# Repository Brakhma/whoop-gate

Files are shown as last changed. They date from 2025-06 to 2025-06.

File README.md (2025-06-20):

# whoop-gate  
Ворота для гонок на маленьких квадрокоптерах.  

**hexgate2.ino** Вторая версия прошивки (кнопка и несколько режимов) под LGT8F328P.  
**hexgate2_nano.ino** Версия прошивки под Arduino nano (отличается только код проверки напряжения батареи).  
**tor4.ino** Флаг с анимацией огня.  

**Фичи:**  
Ворота работают от одной батарейки (любой 1s литий), я использую 18650, какие-либо регуляторы, стабилизаторы step-up не требуются.  
В отличии от ворот на esp минимальное энергопотребление, нет фона на 2,4 GHz  
Есть защита от переразряда батарейки (ворота мигают красным на 3в, на 2.9 засыпают)   
7 режимов свечения перелючаемых по кнопке:  
**Сканер** (как в гексагонах первой версии)   
**Огонь** Анимация огня горящего с двух сторон ленты навстречу друг другу. Если сложить концы ленты вниз то получится огненное кольцо.   
**Радуга** Плавное изменение цвета по всей ленте  
**Фейд** Плавное изменение цвета с затуханием  
**Сплошной красный**  
**Сплошной зелёный**  
**Кометы** По кругу двигаются несколько групп диодов с затухающим хвостом плавно меняющие цвет.  

**Советы**  
Лента используется пятивольтовая WS2812 + и - ленты на холдер батарейки, data на D2 LGT\Arduino. Кнопка замыкает D3 на землю  
Не забудьте указать в коде точное количество диодов.  
LGT прошивайте с clock divider 2  
Для выхода из режимма "сканер" надо нажать кнопку когда светодиоды возвращаются к началу ленты, либо просто нажать и подождать до завершения анимации.  
Ток на воротах зависит от количества диодов и анимации (радуга, фейд, огонь - дороже по энергии, кометы - дешевле)  

Если не знаете что такое LGT и как с ней работать, можете почитать тут:  
[https://alexgyver.ru/lessons/lgt8f328/](https://alexgyver.ru/lessons/lgt8f328/)  
[https://htrd.su/blog/2022/12/04/lgt8fx-lgt8328p/](https://htrd.su/blog/2022/12/04/lgt8fx-lgt8328p/)  
[https://arduino.ru/forum/apparatnye-voprosy/obzor-klona-megi328-lgt8f328p](https://arduino.ru/forum/apparatnye-voprosy/obzor-klona-megi328-lgt8f328p)  
[http://www.prodesign.com.cn/](http://www.prodesign.com.cn/lgt8f328p/)  
  
**UPD** Добавлены модели 19 сантиметровых колец. Кольцо печатается на столе 22х22 без окантовки с кастомной поддержкой (только там где крепится коробка). Заполнение в принципе любое, 10-15 процентов - нормально. Лента WS2812, электроника - LGT8F328P. Клеммы брал [здесь](https://aliexpress.ru/item/1005004432819933.html ) Размеры клеммы в папке с моделью. Количество диодов в прошивке поменяйте под ваш монтаж и плотность ленты, лучше использовать ленту 60led\m. Коробка приклеивается к кольцу суперклеем, к ней привинчивается и, если надо, фиксируется к кольцу на термоклей колдер с клеммами.  
  
[Выглядят вот так](https://t.me/epicwin_ru/109?comment=413).  
[Пример пролёта вот](https://t.me/tagwhoops/1202).  
  
Донаты можно сюда: bc1qfcdmn7tspm0x5qac7ut3yl72tq5az4gx7qjkfs

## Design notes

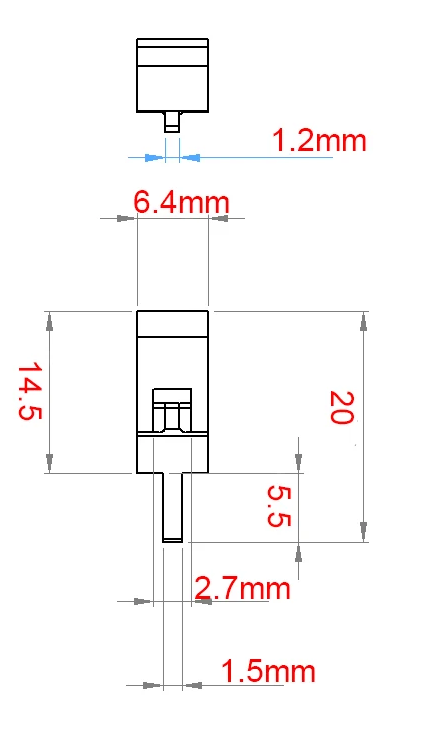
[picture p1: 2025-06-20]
epic_gate(19cm)/klemma.png

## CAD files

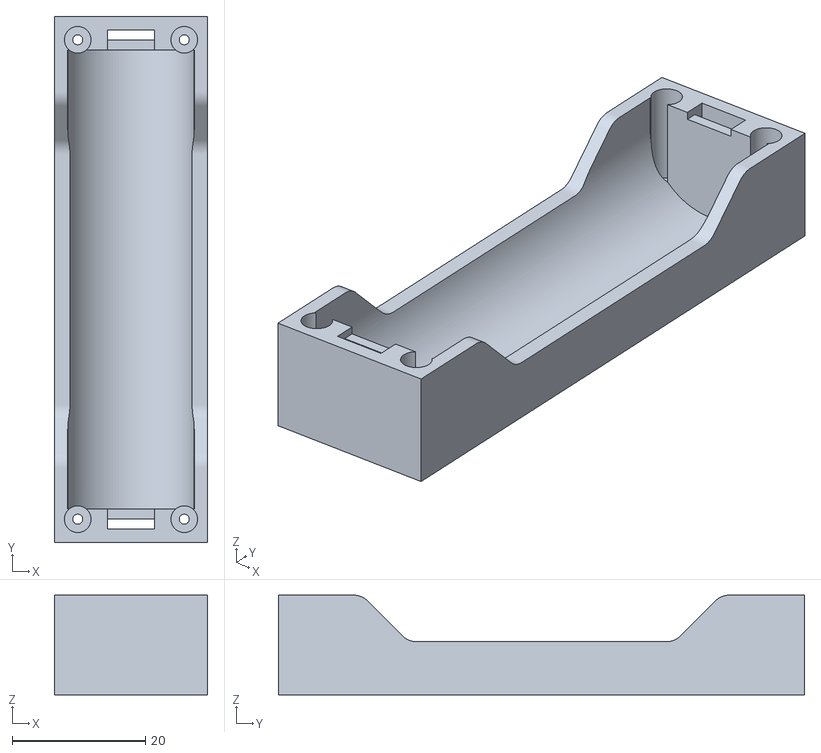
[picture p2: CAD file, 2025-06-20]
epic_gate(19cm)/ring_holder.stl
23.0 x 79.0 x 15.0

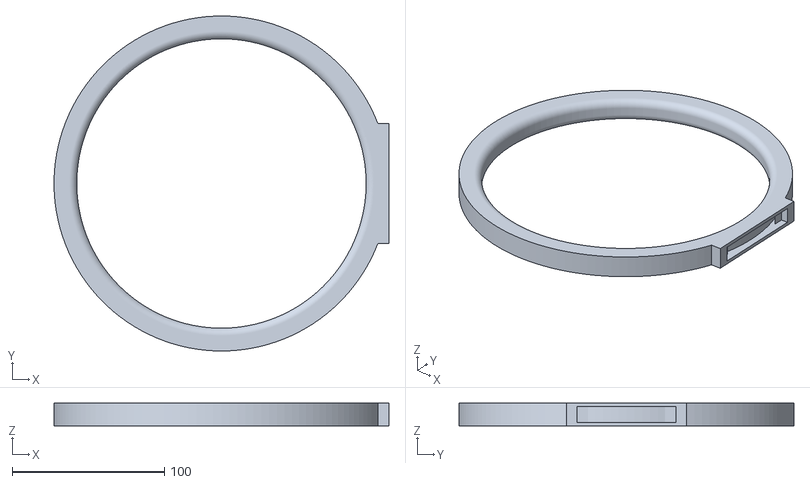
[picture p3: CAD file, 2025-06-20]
epic_gate(19cm)/ring.stl
220.0 x 220.0 x 15.0

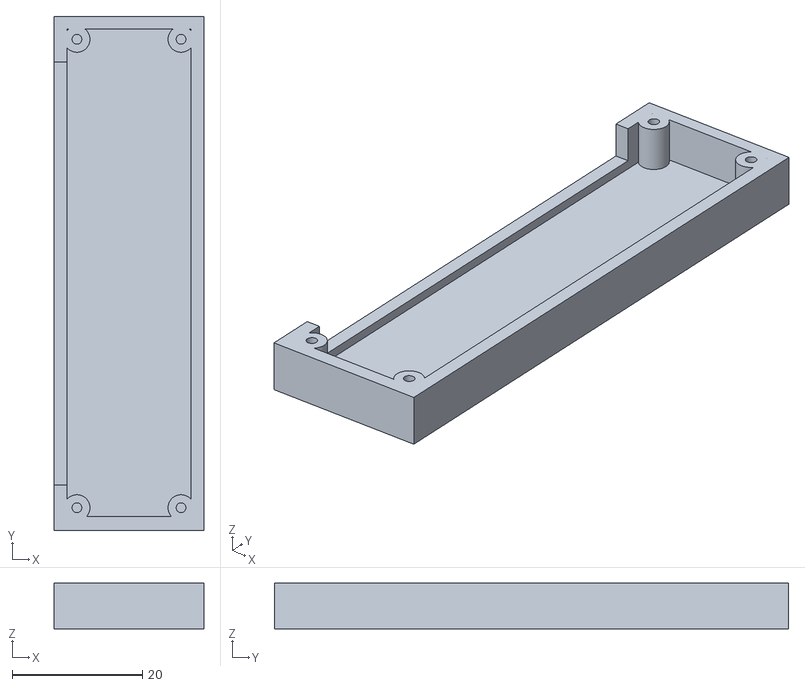
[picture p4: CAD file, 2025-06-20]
epic_gate(19cm)/ring_cap.stl
23.0 x 79.0 x 7.00

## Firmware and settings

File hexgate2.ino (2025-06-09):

#include <FastLED.h>
#include <avr/sleep.h>

#define NUM_LEDS 120 // Количество светодиодов в ленте
#define DATA_PIN 2
#define BUTTON_PIN 3 // Пин для кнопки

// Параметры для эффекта огня
#define COOLING 55 // Охлаждение пламени
#define SPARKING 120 // Вероятность появления искр

int battery_voltage; // Напряжение батареи
int mode = 0; // Переменная для хранения текущего режима
bool buttonPressed = false; // Флаг нажатия кнопки
unsigned long lastDebounceTime = 0; // Время последнего срабатывания кнопки
const unsigned long debounceDelay = 50; // Задержка для антидребезга

CRGB leds[NUM_LEDS]; // Массив для управления светодиодами

void setup() { 
  FastLED.addLeds<WS2812, DATA_PIN, GRB>(leds, NUM_LEDS); // Инициализация ленты
  FastLED.setBrightness(255); // Установка максимальной яркости
  pinMode(BUTTON_PIN, INPUT_PULLUP); // Настройка пина кнопки как вход с подтяжкой
  set_sleep_mode(SLEEP_MODE_PWR_DOWN); // Настройка режима сна
  #if defined(__LGT8FX8P__)
    analogReference(INTERNAL1V024);
  #else
    analogReference(INTERNAL1V25);
  #endif
    analogReadResolution(12);
}

// Функция для плавного уменьшения яркости всех светодиодов
void fadeall() { 
  for(int i = 0; i < NUM_LEDS; i++) { 
    leds[i].nscale8(250); 
  } 
}

// Функция для мигания светодиодов красным цветом (при разряде)
void blink() { 
  for(int i = 0; i < NUM_LEDS; i++) {
    leds[i] = CRGB::Red; // Установка i-го светодиода в красный цвет
    FastLED.show(); // Обновление ленты
  }
  delay(500);

  for(int i = 0; i < NUM_LEDS; i++) {
    leds[i] = CRGB::Black; // Выключение i-го светодиода
    FastLED.show();
  }
  delay(500);

  battery_voltage = readVcc(); // Чтение напряжения батареи
  if (battery_voltage < 2900) { // Если напряжение ниже 2.9V
    sleep_mode(); // Переход в режим сна
  }
  blink();
}

// Функция для чтения напряжения батареи
long readVcc() {
  uint32_t v = analogRead(VCCM);
    
    // convert to VCC (unit: mV);
  #if defined(__LGT8FX8P__)
    v = (v * 5 ) / 4 ;
  #else
    v = (v * 5000 ) / 4096 ;
  #endif
  return v;
}

// Режим 0: Изначальный режим (движение светодиодов в одном направлении и обратно)
void originalMode() {
  static uint8_t hue = 0; // Переменная для хранения оттенка цвета

  // Движение светодиодов в одном направлении
  for(int i = 0; i < NUM_LEDS; i++) {
    leds[i] = CHSV(hue++, 255, 255); // Установка i-го светодиода в цвет с оттенком hue
    FastLED.show(); // Обновление ленты
    fadeall(); // Плавное уменьшение яркости
    delay(10);
  }

  // Движение светодиодов в обратном направлении
  for(int i = NUM_LEDS - 1; i >= 0; i--) {
    leds[i] = CHSV(hue++, 255, 255); // Установка i-го светодиода в цвет с оттенком hue
    FastLED.show();
    fadeall(); 
    delay(10);
  }
}

// Режим 1: Огонь (горение с двух концов ленты)
void fire() {
  static uint8_t heat[NUM_LEDS / 2]; // Массив для хранения "температуры" пламени

  // Охлаждение каждого пикселя
  for (int i = 0; i < NUM_LEDS / 2; i++) {
    heat[i] = qsub8(heat[i], random8(0, ((COOLING * 10) / (NUM_LEDS / 2)) + 2));
  }

  // Распространение тепла
  for (int k = (NUM_LEDS / 2) - 1; k >= 2; k--) {
    heat[k] = (heat[k - 1] + heat[k - 2] + heat[k - 2]) / 3;
  }

  // Добавление новых искр
  if (random8() < SPARKING) {
    int y = random8(7);
    heat[y] = qadd8(heat[y], random8(160, 255));
  }

  // Отображение пламени с двух концов ленты
  for (int j = 0; j < NUM_LEDS / 2; j++) {
    CRGB color = HeatColor(heat[j]);
    leds[j] = color;
    leds[NUM_LEDS - 1 - j] = color;
  }

  FastLED.show();
  FastLED.delay(20);
}

// Режим 2: Радуга
void rainbow() {
  static uint8_t hue = 0;
  for(int i = 0; i < NUM_LEDS; i++) {
    leds[i] = CHSV(hue + i * 5, 255, 255); // Радужный эффект
  }
  FastLED.show();
  hue++;
  delay(10);
}

// Режим 3: Плавное изменение цвета
void colorFade() {
  static uint8_t hue = 0;
  fill_solid(leds, NUM_LEDS, CHSV(hue, 255, 255)); // Плавное изменение цвета
  FastLED.show();
  hue++;
  delay(20);
}

// Режим 4: Красный цвет
void redColor() {
  fill_solid(leds, NUM_LEDS, CRGB::Red); // Заполнение ленты красным цветом
  FastLED.show();
}

// Режим 5: Зелёный цвет
void greenColor() {
  fill_solid(leds, NUM_LEDS, CRGB::Green); // Заполнение ленты зелёным цветом
  FastLED.show();
}

// Режим "Кометы" 
void comets() {
  const int numComets = 4; // Количество комет
  const int cometSize = 10 ; // Длина хвоста кометы
  static uint8_t hue = 0; // Переменная для хранения оттенка цвета
  static int cometPositions[numComets]; // Позиции комет
  static uint8_t cometHues[numComets]; // Цвета комет

  // Инициализация позиций и цветов комет при первом запуске
  static bool firstRun = true;
  if (firstRun) {
    for (int i = 0; i < numComets; i++) {
      cometPositions[i] = i * (NUM_LEDS / numComets); // Равномерное распределение комет
      cometHues[i] = random(255); // Случайный начальный цвет
    }
    firstRun = false;
  }

  // Очистка ленты (вся лента тёмная)
  fill_solid(leds, NUM_LEDS, CRGB::Black);

  // Отрисовка комет с хвостами
  for (int i = 0; i < numComets; i++) {
    // Двигаем комету
    cometPositions[i] = (cometPositions[i] + 1) % NUM_LEDS;

    // Рисуем комету с хвостом
    for (int j = 0; j < cometSize; j++) {
      int pos = (cometPositions[i] - j + NUM_LEDS) % NUM_LEDS; // Позиция с учётом хвоста
      uint8_t brightness = 255 * (cometSize - j) / cometSize; // Явное затухание яркости хвоста
      leds[pos] = CHSV(cometHues[i], 255, brightness); // Цвет с затуханием
    }

    // Меняем цвет кометы
    cometHues[i] += 5;
  }

  FastLED.show();
  delay(50); // Задержка для скорости движения
}

void loop() { 
  // Чтение состояния кнопки с антидребезгом
  int reading = digitalRead(BUTTON_PIN);
  if (reading == LOW) { // Если кнопка нажата (LOW, так как подключена к GND)
    if (!buttonPressed && (millis() - lastDebounceTime) > debounceDelay) {
      buttonPressed = true;
      lastDebounceTime = millis();
      mode = (mode + 1) % 7; // Переключение режима (теперь 6 режимов)
    }
  } else {
    buttonPressed = false;
  }

  // Выбор режима в зависимости от значения переменной mode
  switch (mode) {
    case 0:
      originalMode(); // гекса
      break;
    case 1:
      fire(); // Огонь с двух концов ленты
      break;
    case 2:
      rainbow(); // Радуга
      break;
    case 3:
      colorFade(); // Плавное изменение цвета
      break;
    case 4:
      comets(); // Кометы
      break;
    case 5:
      redColor(); // Красный цвет
      break;
    case 6:
      greenColor(); // Зелёный цвет
      break;
  }

  // Проверка напряжения батареи
  battery_voltage = readVcc();
  if (battery_voltage < 3000) { // Если напряжение ниже 3.0V
    battery_voltage = readVcc(); // Повторное чтение для исключения случайных значений
    if (battery_voltage < 3000) { // Если напряжение всё ещё ниже 3.0V
      blink();
    }
  }
}

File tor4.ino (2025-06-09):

#include <FastLED.h>
#include <avr/sleep.h>

#define NUM_LEDS 46 //67 //88
#define NUM_LEDS_TMP 23 //первая колонка

#define DATA_PIN 2
int battery_voltage;

// COOLING: How much does the air cool as it rises?
// Less cooling = taller flames.  More cooling = shorter flames.
// Default 50, suggested range 20-100 
#define COOLING  55

// SPARKING: What chance (out of 255) is there that a new spark will be lit?
// Higher chance = more roaring fire.  Lower chance = more flickery fire.
// Default 120, suggested range 50-200.
#define SPARKING 120

// Define the array of leds
CRGB leds[NUM_LEDS];

void setup() { 
	Serial.begin(57600);
	Serial.println("resetting");
	FastLED.addLeds<WS2812,DATA_PIN,GRB>(leds,NUM_LEDS);
	FastLED.setBrightness(255);
  set_sleep_mode(SLEEP_MODE_PWR_DOWN);
  #if defined(__LGT8FX8P__)
    analogReference(INTERNAL1V024);
  #else
    analogReference(INTERNAL1V25);
  #endif
    analogReadResolution(12);
}

void blink() { 
  for(int i = 0; i < NUM_LEDS; i++) {
    // Set the i'th led to red 
    leds[i] = CRGB::Red; 
    // Show the leds
    FastLED.show(); }
    delay(500);
  for(int i = 0; i < NUM_LEDS; i++) {
    // Set the i'th led to red 
    leds[i] = CRGB::Black;
    // Show the leds
    FastLED.show(); }
  delay(500);
  
  battery_voltage = readVcc();
  Serial.println(battery_voltage);
    if (battery_voltage< 2900){sleep_mode();}
  blink();
}

long readVcc() {
  uint32_t v = analogRead(VCCM);
    
    // convert to VCC (unit: mV);
  #if defined(__LGT8FX8P__)
    v = (v * 5 ) / 4 ;
  #else
    v = (v * 5000 ) / 4096 ;
  #endif
  return v;
}

void Fire2012()
{
// Array of temperature readings at each simulation cell

  static uint8_t heat[NUM_LEDS_TMP];

  // Step 1.  Cool down every cell a little
    for( int i = 0; i < NUM_LEDS_TMP; i++) {
      heat[i] = qsub8( heat[i],  random8(0, ((COOLING * 10) / NUM_LEDS_TMP) + 2));
    }
  
    // Step 2.  Heat from each cell drifts 'up' and diffuses a little
    for( int k= NUM_LEDS_TMP - 1; k >= 2; k--) {
      heat[k] = (heat[k - 1] + heat[k - 2] + heat[k - 2] ) / 3;
    }
    
    // Step 3.  Randomly ignite new 'sparks' of heat near the bottom
    if( random8() < SPARKING ) {
      int y = random8(7);
      heat[y] = qadd8( heat[y], random8(160,255) );
    }

    // Step 4.  Map from heat cells to LED colors
    for( int j = 0; j < NUM_LEDS_TMP; j++) {
      CRGB color = HeatColor( heat[j]);
      leds[j] = color;
    }

    // Step 5. Map from heat cells to LED colors for the inverted second row
    for (int j = 0; j < NUM_LEDS_TMP; j++) {
      CRGB color = HeatColor(heat[j]);
      int pixelnumber = NUM_LEDS-1-j; // Direct mapping for the second row
      leds[pixelnumber] = color; // Assuming leds2 is defined and represents the second row
    }
}

void loop() { 

  Fire2012(); // run simulation frame
  FastLED.show(); // display this frame
  FastLED.delay(20);
  
		// now that we've shown the leds, reset the i'th led to black
		// leds[i] = CRGB::Black;
		// Wait a little bit before we loop around and do it again
	//Serial.print("x");

  
    battery_voltage = readVcc();
    Serial.println(battery_voltage);
    if (battery_voltage< 3000){
      battery_voltage = readVcc(); 
      if (battery_voltage< 3000){ //нужна перепроверка потому что иногда (редко) может поймать рандомное значение
        blink();}}
      
    
	}

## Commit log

2025-06-09 Это вторая версия прошивки под Arduino nano.
2025-06-09 Add files via upload
    Вторая версия прошивки (кнопка и несколько режимов) под LGT8F328P.
2025-06-09 Факел
    Флаг с анимацией огня.
2025-06-20 Модель 19см кольца
    [ring.stl, ring_cap.stl, ring_holder.stl]
